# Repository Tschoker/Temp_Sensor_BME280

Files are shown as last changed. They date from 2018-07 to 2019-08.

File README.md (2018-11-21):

# Solar powered Weather Station
## Idea
Building a weather station that sends temperature, humidity and airpressure via MQTT to a server via WLAn connection while powered only by a solar panel and a 18650 Accu for long term operation without need of recharge.
## Components
- NodeMCU v3
- BME280 Sensor
- TP4056 charger module
- 5V solar panel
- 1N5817 diode
- 18650 Accu + Battery holder
- Resistor 200k

## Schematics
The solat panel is connected to the charger module inputs with the diode to protect reverse current through the solar panel during dark hours. The Accu is connected to the battery pins of the charger module. The output pins of the charger module are connected to the Vin and GND connectors of the nodemcu.
Pin D0 is shortened with RST to enable the deepsleep functionality.
Pin D1, D2 are used to connect SCL and SDA of the BME280 module.
Pin D3 is used to provide power for the BME module and is only activated when needed.
Pin A0 is connected with 200k against VIN (currently not in the pictures) to measure battery level. Code needs to be adapted to actual values. Code constant (5.03148F) calculates by measuring all resistors (the one placed - R1, and the ones on the board between A0 and ADC pin on the ESP - R2 - as well as between GND and the ADC pin of the ESP - R3) and calculate:
(R1+R2+R3)/R3
If thats not measuring exact enough you can divide the actual Vin by the measured value from ESP and multiply your current value with it. So when your resistor calculation results in 5.123, your ESP measures 4.0 but actually your battery has 4.2 your new factor will be:
5.123 * 4.2 / 4.0

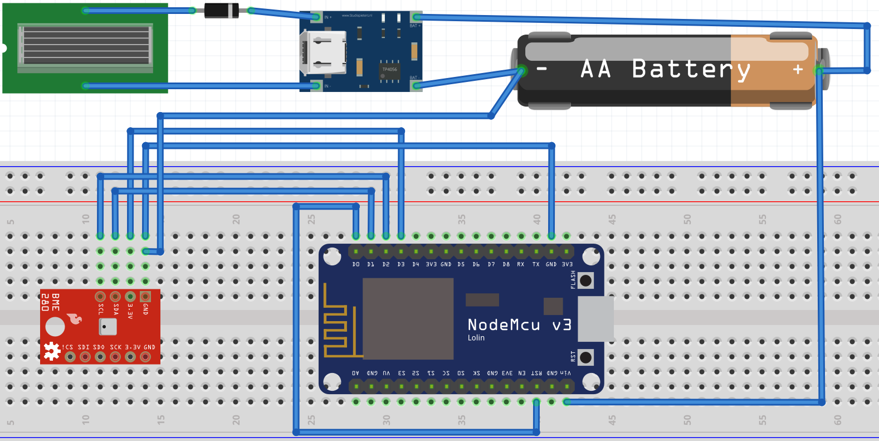
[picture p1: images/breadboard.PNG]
Breadboard


## Code
Please rename the config.cpp.template to config.cpp and set your coresponding credentials and parameters.
The calculation for the battery level needs to be adapted for actual resistor values.

## Images
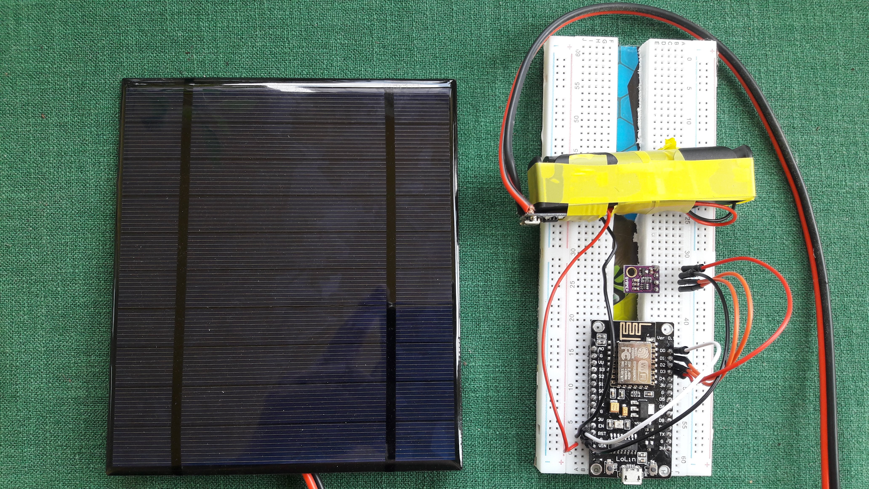
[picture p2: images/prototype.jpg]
Prototype


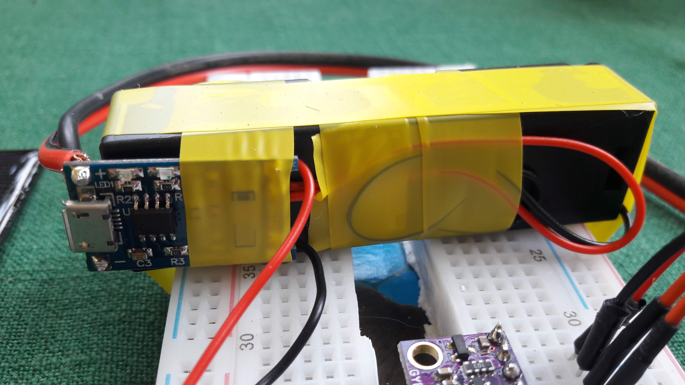
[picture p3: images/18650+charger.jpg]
18650+Charger


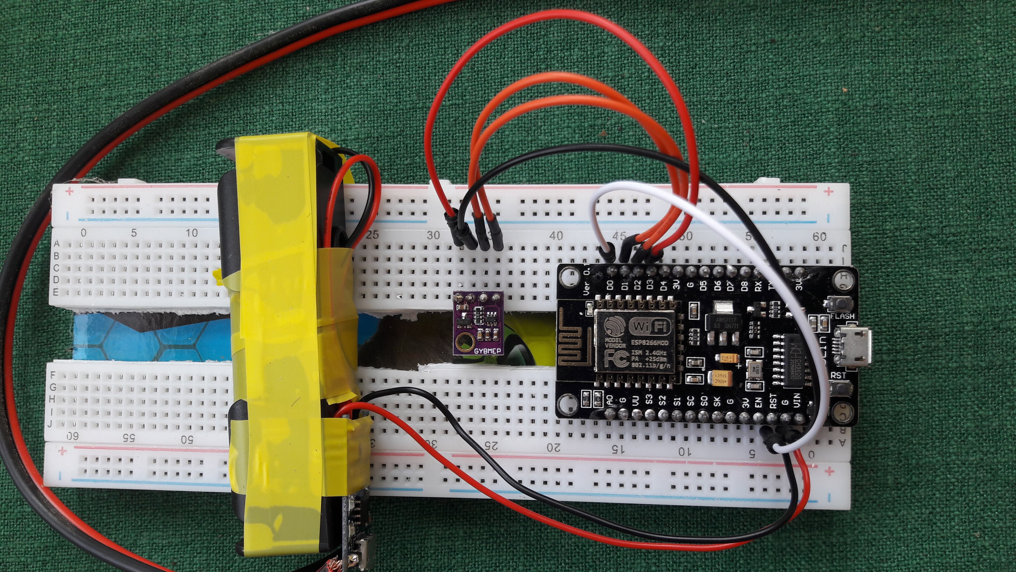
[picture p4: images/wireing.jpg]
wireing


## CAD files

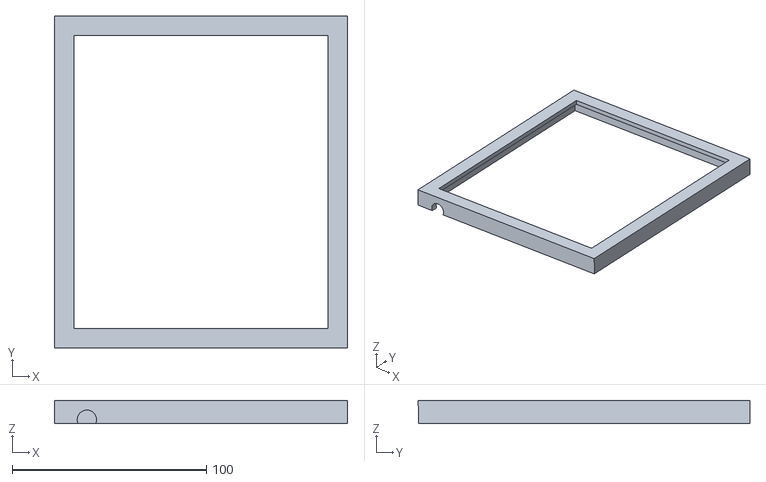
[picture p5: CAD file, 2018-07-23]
3d print/solar_oberteil.stl
151.0 x 171.0 x 12.0

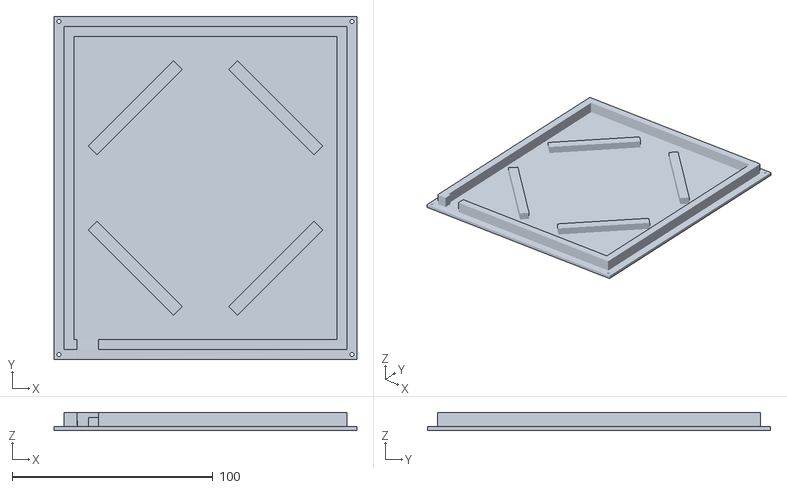
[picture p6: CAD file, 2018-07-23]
3d print/solar_unterteil.stl
151.0 x 171.0 x 9.13

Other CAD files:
3d print/solar.blend

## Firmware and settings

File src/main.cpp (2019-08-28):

#include <Arduino.h>
#include <Wire.h>
#include <Adafruit_BME280.h>
#include <ESP8266WiFi.h>
#include <PubSubClient.h>

#include <config.cpp>

//D0 = Output for RST pin
//D1 = I2C CLK
//D2 = I2C SDA
//D3 = pwr supply BME280

Adafruit_BME280 bme;

WiFiClient espClient;
PubSubClient client(espClient);

float temp = 0.0;
float hum = 0.0;
float pressure = 0.0;
float bat = 0.0;
bool status;

void setup_wifi() {
 delay(10);
 // We start by connecting to a WiFi network
 Serial.println();
 Serial.print("Connecting to ");
 Serial.println(wifi_ssid);
 WiFi.begin(wifi_ssid, wifi_password);
 while (WiFi.status() != WL_CONNECTED) {
  delay(500);
  Serial.print(".");
 }
 Serial.println("");
 Serial.println("WiFi connected");
 Serial.println("IP address: ");
 Serial.println(WiFi.localIP());
}

void reconnect() {
 // Loop until we're reconnected
 while (!client.connected()) {
  Serial.print("Attempting MQTT connection...");
  // Attempt to connect
  if (client.connect("nodemcu", mqtt_user, mqtt_password, will_topic, 0, 1, "false")) {
  Serial.println("connected");
  client.publish(will_topic, "true");
  delay(10);
  } else {
  Serial.print("failed, rc=");
  Serial.print(client.state());
  Serial.println(" try again in 2 seconds");
  delay(2000);
  }
 }
}

void setup()
{
  //initialize serial
  Serial.begin(74880);
  while (!Serial); // Leonardo: wait for serial monitor

  //Activate power supply for sensor
  pinMode(D3,OUTPUT);
  digitalWrite(D3,HIGH);
  delay(50);
  Serial.println("Sensor powered on");

  //initiate WiFi
  setup_wifi();

  //connect MQTT
  client.setServer(mqtt_server, 1883);
  if (!client.connected()) {
   Serial.println("MQTT not connected - trying reconnect!");
   reconnect();
  }
  client.loop();

  //Connect sensor
  Wire.begin(D1, D2);
  status = bme.begin(0x76);
  if (!status) {
     Serial.println("Could not find a valid BME280 sensor, check wiring!");
  }

  //read and send values
  Serial.println(F("BME280 values"));
  temp=bme.readTemperature();
  pressure=(bme.readPressure()/100.0F);
  hum=bme.readHumidity();
  //bat=analogRead (A0) / 1024.0F * 5.03148F; //see README how to calculate your value for 5.03148F

  Serial.println( String(temp).c_str());
  client.publish(temperature_topic, String(temp).c_str(), true);
  Serial.println( String(pressure).c_str());
  client.publish(pressure_topic, String(pressure).c_str(), true);
  Serial.println(String(hum).c_str());
  client.publish(humidity_topic, String(hum).c_str(), true);
  //Serial.println(String(bat).c_str());
  //client.publish(battery_topic, String(bat).c_str(), true);

  delay(100);


  //deactivate sensor pwr supply
  digitalWrite(D3,LOW);

  client.publish(will_topic, "false", true);
  delay(1000);
  //go to sleep
  ESP.deepSleep(900e6);

}


void loop()
{

}

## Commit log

2018-07-23 3d prints
    [solar.blend, solar_oberteil.stl, solar_unterteil.stl]
2018-07-24 Battery monitor added
    Code updated, schematic missing
    [main.cpp]
2018-07-24 Battery monitoring added
2018-07-25 Adapted battery measurement
2018-11-27 Increased intervall to 15min. Deactivated Battery measurement
